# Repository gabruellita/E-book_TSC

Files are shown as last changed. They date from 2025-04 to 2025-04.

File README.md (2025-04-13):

# OpenBook E-Book Reader

Bine ați venit la proiectul OpenBook, un cititor de e-bookuri open-source, accesibil, conceput pentru a face lectura disponibilă tuturor. Acest repository conține fișierele de design hardware, fișierele de fabricație, modelele mecanice și documentația pentru dispozitivul OpenBook.

## Cuprins

- [Prezentare Proiect](#prezentare-proiect)
- [Diagramă Bloc](#diagrama-bloc)
- [Lista de Materiale (BOM)](#lista-de-materiale-bom)
- [Funcționalitate Hardware](#functionalitate-hardware)
- [Alocarea Pinilor ESP32-C6](#alocarea-pinilor-esp32-c6)
- [Note de Design](#note-de-design)
- [Licență](#licenta)

## Prezentare Proiect

OpenBook este un cititor de e-bookuri open-source bazat pe microcontrolerul ESP32-C6. Dispozitivul include un display e-paper, stocare pe card SD pentru e-bookuri, o interfață USB-C pentru alimentare și date, și un design compact care se potrivește într-o carcasă personalizată. Scopul este crearea unui e-reader ieftin, modificabil, care poate fi produs în masă, respectând principiile open-source.

Acest repository conține:

- **Hardware**: Fișiere pentru schemă electrică și PCB.
- **Manufacturing**: Fișiere Gerber, Lista de Materiale (BOM) și fișiere Pick and Place.
- **Mechanical**: Modele 3D ale dispozitivului complet (PCB, baterie, display și carcasă).
- **Images**: Randări ale PCB-ului și dispozitivului.

## Diagramă Bloc

Mai jos este o diagramă bloc care ilustrează componentele principale și conexiunile lor:

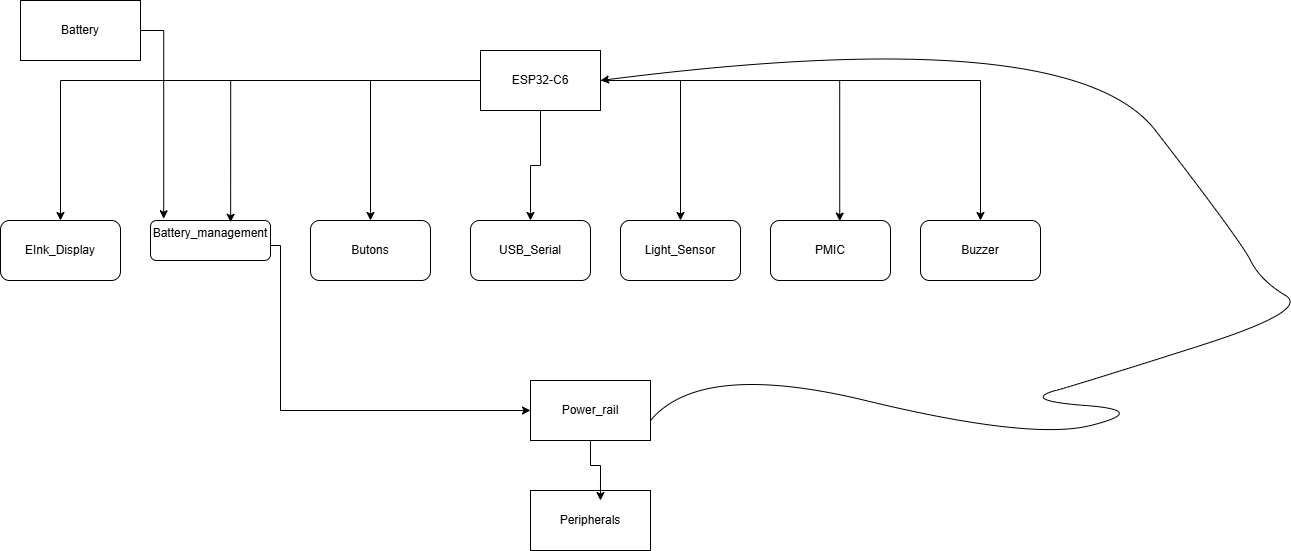
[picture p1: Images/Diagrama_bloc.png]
Diagramă Bloc


*(Notă: Creează o diagramă folosind Draw.io sau Lucidchart, export-o ca PNG și încarc-o în folderul `Images`. Actualizează link-ul de mai sus dacă numele fișierului este diferit.)*

## Lista de Materiale (BOM)

Tabelul următor listează componentele folosite în designul OpenBook, cu link-uri către furnizori și datasheet-uri.

| Componentă | Număr Piesă | Cantitate | Link Furnizor | Link Datasheet | Note |
|---|---|---|---|---|---|
| Senzor mediu | BME680 | 1 | [SnapEDA](https://www.snapeda.com/parts/BME680/Bosch/view-part/?welcome=home) | [Bosch](https://www.bosch-sensortec.com/media/boschsensortec/downloads/datasheets/bst-bme680-ds001.pdf) | Senzor temperatură, umiditate |
| Buton tactil | EVQPUJ02K | 3 | [Panasonic](https://industry.panasonic.com/global/en/products/control/switch/light-touch/number/evqpuj02k) | [LCSC](https://www.lcsc.com/datasheet/lcsc_datasheet_2201121800_PANASONIC-EVQPUJ02K_C2936858.pdf) | Butoane navigare și pornire |
| Condensator | R0402 100K | [TBD] | [ComponentSearch](https://componentsearchengine.com/part-view/R0402%201%25%20100%20K%20(RC0402FR-07100KL)/YAGEO) | [Resistor](https://www.resistor.com/assets/pdf/0402tstd.pdf) | Condensator decuplare, SMD 0402 |
| Rezistor | R0402 100K | [TBD] | [ComponentSearch](https://componentsearchengine.com/part-view/R0402%201%25%20100%20K%20(RC0402FR-07100KL)/YAGEO) | [Resistor](https://www.resistor.com/assets/pdf/0402tstd.pdf) | Rezistor, SMD 0402 |
| Baterie | CPH3225A | 1 | [SnapEDA](https://www.snapeda.com/parts/CPH3225A/Seiko+Instruments/view-part/?ref=eda) | [Octopart](https://octopart.com/datasheet/cph3225a-seiko-25340571) | Baterie Li-Po, ~500mAh |
| LED | KP-1608SURCK | 1 | [SnapEDA](https://www.snapeda.com/parts/KP-1608SURCK/Kingbright/view-part/?ref=search&t=LED%200603) | [ELV](https://media.elv.com/file/107153_led_surck1608_data.pdf) | LED 0603, indicator |
| Protecție ESD | USBLC6-2SC6Y | 1 | [SnapEDA](https://www.snapeda.com/parts/USBLC6-2SC6Y/STMicroelectronics/view-part/?ref=eda) | [DigiKey](https://www.digikey.com/en/htmldatasheets/production/1375342/0/0/1/usblc6-2sc6y) | Protecție USB |
| Diodă Schottky | SD0805S020S1R0 | 1 | [Mouser](https://ro.mouser.com/ProductDetail/KYOCERA-AVX/SD0805S020S1R0?qs=jCA%252BPfw4LHbpkAoSnwrdjw%3D%3D) | [AllDataSheet](https://www.alldatasheet.com/view.jsp?Searchword=SD0805S&sField=2) | Diodă pentru alimentare |
| Supresor ESD | PGB1010603MR | 1 | [SnapEDA](https://www.snapeda.com/parts/PGB1010603MR/Littelfuse/view-part/?ref=eda) | [AllDataSheet](https://www.alldatasheet.com/view.jsp?Searchword=Pgb1010603mr) | Protecție ESD |
| Detector tensiune | BD5229G-TR | 1 | [ComponentSearch](https://componentsearchengine.com/part-view/BD5229G-TR/ROHM%20Semiconductor) | [LCSC](https://www.lcsc.com/datasheet/lcsc_datasheet_2201131330_ROHM-Semicon-BD5229G-TR_C962636.pdf) | Monitorizare tensiune |
| Regulator tensiune | XC6220A331MR-G | 1 | [ComponentSearch](https://componentsearchengine.com/part-view/XC6220A331MR-G/Torex) | [AllDataSheet](https://www.alldatasheet.com/view.jsp?Searchword=Xc6220) | Regulator 3.3V |
| Conector USB-C | USB4110-GF-A | 1 | [ComponentSearch](https://componentsearchengine.com/part-view/USB4110-GF-A/GCT%20(GLOBAL%20CONNECTOR%20TECHNOLOGY)) | [GCT](https://gct.co/files/drawings/usb4110.pdf) | Interfață USB-C |
| LED | LEDCHIP-LED0603 | 1 | [Mouser](https://eu.mouser.com/ProductDetail/Adafruit/4208?qs=PzGy0jfpSMtbScLbr0L5dw%3D%3D) | [Arrow](https://www.arrow.com/en/manufacturers/adafruit-industries/datasheets) | LED 0603, Adafruit |
| Bobină | [TBD] | 1 | [Comet](https://store.comet.srl.ro/Catalogue/Product/43497/) | [Scribd](https://www.scribd.com/document/814581278/Datasheet-Bobina) | Inductor pentru alimentare |
| Siguranță resetabilă | PFMF | 1 | [Mouser](https://www.mouser.co.uk/ProductDetail/EPCOS-TDK/B72520T0350K062?qs=dEfas%2FXlABIszF52uu7vrg%3D%3D) | [Mouser](https://ro.mouser.com/c/ds/circuit-protection/thermistors/resettable-fuses-pptc/?m=Schurter&series=PFMF) | Protecție circuit |
| MOSFET | DMG2305UX-7 | 1 | [ComponentSearch](https://componentsearchengine.com/part-view/DMG2305UX-7/Diodes%20Incorporated) | [Mouser](https://www.mouser.com/datasheet/2/115/DMG2305UX-266242.pdf) | Comutare putere |
| MOSFET | Si1308EDL-T1-GE3 | 1 | [ComponentSearch](https://componentsearchengine.com/part-view/SI1308EDL-T1-GE3/Vishay) | [AllDataSheet](https://www.alldatasheet.com/view.jsp?Searchword=Si1308edl) | Comutare putere |
| IC management baterie | MCP73831T-5ACI/OT | 1 | [Mouser](https://www.mouser.co.uk/ProductDetail/Microchip-Technology/MCP73831T-5ACI-OT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) | [Microchip](https://ww1.microchip.com/downloads/en/DeviceDoc/MCP73831-Family-Data-Sheet-DS20001984H.pdf) | Încărcare baterie |
| Lipire SMD | SMD Solder | [TBD] | [GrabCAD](https://grabcad.com/library/solder-jumpers-1) | - | Pentru asamblare SMD |
| Memorie flash | W25Q512JVEIQ | 1 | [SnapEDA](https://www.snapeda.com/parts/W25Q512JVEIQ/Winbond+Electronics/view-part/) | [Mouser](https://www.mouser.com/datasheet/2/949/W25Q512JV_SPI_RevB_06252019_KMS-2487502.pdf) | Memorie SPI |
| Modul microcontroler | ESP32-C6-WROOM-1-N8 | 1 | [SnapEDA](https://www.snapeda.com/parts/ESP32-C6-WROOM-1-N8/Espressif+Systems/view-part/?ref=eda) | [Mouser](https://www.mouser.com/catalog/specsheets/Espressif_ESP32_C6_WROOM_1%20_Datasheet_V0.1_PRELIMINARY_en.pdf) | Modul Wi-Fi/Bluetooth |
| Ceas timp real | DS3231SN# | 1 | [SnapEDA](https://www.snapeda.com/parts/DS3231SN%23/Analog+Devices/view-part/?ref=eda) | [AllDataSheet](https://www.alldatasheet.com/view.jsp?Searchword=Ds3231sn%20datasheet) | RTC pentru timp |
| Monitor baterie | MAX17048G+T10 | 1 | [SnapEDA](https://www.snapeda.com/parts/MAX17048G+T10/Analog+Devices/view-part/?ref=eda) | [AllDataSheet](https://www.alldatasheet.com/view.jsp?Searchword=Max17048) | Monitorizare nivel baterie |

## Funcționalitate Hardware

Hardware-ul OpenBook este proiectat pentru a echilibra costul, eficiența energetică și funcționalitatea. Caracteristicile principale includ:

- **Microcontroler ESP32-C6**:
  - **Nucleu**: Procesor RISC-V single-core.
  - **Conectivitate**: Wi-Fi 6 și Bluetooth 5 pentru actualizări de firmware sau integrare cloud.
  - **Interfețe**: SPI pentru display și card SD, GPIO pentru butoane, USB pentru alimentare și depanare.
  - **Consum de energie**: Optimizat pentru funcționare cu consum redus, cu moduri de sleep pentru a prelungi durata bateriei.

- **Display E-Paper**:
  - Display e-paper de 2.13" (rezoluție [TBD, ex. 250x122 pixeli]).
  - Conectat prin SPI pentru actualizare rapidă și consum redus.
  - Ideal pentru citit în diverse condiții de iluminare, cu consum minim.

- **Modul Card SD**:
  - Stochează e-bookuri și alte fișiere media.
  - Conectat prin SPI pentru transfer de date fiabil.
  - Suportă carduri microSD standard.

- **Interfață USB-C**:
  - Furnizează alimentare (intrare 5V) și încarcă bateria prin IC-ul de management al puterii.
  - Suportă transfer de date pentru depanare sau actualizări de firmware.

- **Baterie și Management Putere**:
  - Baterie Li-Po de 3.7V (~500mAh, capacitate exactă [TBD]).
  - IC de management al puterii (ex. TP4056) gestionează încărcarea și reglarea tensiunii (3.3V pentru ESP32 și alte componente).
  - Durata estimată a bateriei: [TBD, ex. 20 ore de citire activă], bazată pe calcule pentru actualizarea display-ului, modurile sleep ale ESP32 și accesul la cardul SD.

- **Butoane**:
  - Trei butoane tactile pentru navigare (următoarea/pagina anterioară) și pornire/meniu.
  - Conectate la pinii GPIO ai ESP32 cu rezistoare pull-up.

- **Calcule Consum Energie**:
  - ESP32-C6 (activ): ~100mA la 3.3V.
  - Display E-Paper (actualizare): ~10mA pentru 1s per pagină.
  - Card SD (citire): ~50mA în timpul accesului.
  - Consum total activ: [TBD, ex. ~150mA mediu].
  - Mod sleep: [TBD, ex. <1mA].

*(Notă: Actualizează consumul de energie și alte specificații pe baza alegerilor tale de design și a datasheet-urilor.)*

## Alocarea Pinilor ESP32-C6

Pinii ESP32-C6 sunt alocați astfel:

| Pin | Funcție | Componentă/Modul | Note |
|---|---|---|---|
| GPIO0 | SPI MOSI | Display E-Paper, Card SD| Bus SPI comun |
| GPIO1 | SPI MISO | Display E-Paper, Card SD| Bus SPI comun |
| GPIO2 | SPI SCK | Display E-Paper, Card SD| Bus SPI comun |
| GPIO3 | SPI CS (Display) | Display E-Paper | Selectare cip pentru display |
| GPIO4 | SPI CS (Card SD) | Modul Card SD | Selectare cip pentru card SD |
| GPIO5 | Buton 1 (Pagina Urm.) | Buton Tactil | Pull-up, activ low |
| GPIO6 | Buton 2 (Pagina Ant.) | Buton Tactil | Pull-up, activ low |
| GPIO7 | Buton 3 (Pornire/Meniu) | Buton Tactil | Pull-up, activ low |
| GPIO8 | Reset Display | Display E-Paper | Activ low |
| GPIO9 | Busy Display | Display E-Paper | Intrare de la display |
| VBUS | Alimentare USB | Conector USB-C | Intrare 5V |
| 3V3 | Linie Alimentare | Toate componentele | Reglat din baterie/USB |

*(Notă: Verifică alocarea pinilor față de schemă. Actualizează tabelul cu numerele exacte ale pinilor și funcțiile pe baza designului tău.)*

### De ce acești pini?

- **Pini SPI (GPIO0-4)**: Aleși pentru suportul hardware dedicat SPI, asigurând comunicație rapidă și fiabilă cu display-ul și cardul SD. Un bus SPI comun minimizează utilizarea pinilor.
- **Pini Butoane (GPIO5-7)**: Selectați pentru capabilitățile de intrare generală și suport pentru întreruperi, permițând interacțiune rapidă cu utilizatorul.
- **Pini Control Display (GPIO8-9)**: Folosiți pentru semnalele de reset și busy, conform cerințelor datasheet-ului display-ului e-paper.
- **Pini Alimentare (VBUS, 3V3)**: Standard pentru livrarea și reglarea energiei.

## Note de Design

- **Schemă și Design PCB**:
  - Schema (`Hardware/openbook.sch`) respectă referința furnizată.
  - Layout-ul PCB (`Hardware/openbook.brd`) respectă constrângerile mecanice, cu toate componentele pe stratul TOP și rutarea pe ambele straturi TOP și BOTTOM.
  - Traseele de alimentare folosesc lățimea de 0.3mm, iar traseele de semnal au lățimea minimă de 0.15mm, conform ghidului.
  - Antena ESP32-C6 este poziționată la marginea PCB-ului, cu o decupare dedesubt pentru a minimiza interferențele.

- **Design Mecanic**:
  - Modelul 3D (`Mechanical/openbook.step`) include PCB-ul, bateria, display-ul e-paper și carcasa modificată.
  - Bateria se conectează direct la pad-uri de test (fără conector JST) pentru a economisi spațiu.
  - Carcasa a fost modificată pentru a alinia portul USB-C și slotul pentru card SD (detalii în folderul `Mechanical`).

- **Provocări și Decizii**:
  - **erori DRC**: Ignorate erorile „Only INPUT pins on NET ID” și erorile de dimensiune pentru butoane/USB, conform ghidului, deoarece nu afectează funcționalitatea.
  - **Amplasare componente**: Componentele au fost grupate în jurul ESP32 și al driverului display-ului pentru a minimiza lungimea traseelor și a îmbunătăți integritatea semnalului.
  - **Via Stitching**: Aplicat între planurile de masă TOP și BOTTOM lângă ESP32 pentru a îmbunătăți performanța EMI.
  - **Silkscreen**: Include doar numele componentelor (nu și valorile) pentru claritate, respectând bunele practici.

## Licență

Acest proiect este licențiat sub [GNU General Public License v3.0](LICENSE). Puteți utiliza, modifica și distribui designul, cu condiția respectării termenilor licenței.

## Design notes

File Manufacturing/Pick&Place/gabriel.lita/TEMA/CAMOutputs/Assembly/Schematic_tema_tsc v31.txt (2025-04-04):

Partlist exported from Fusion Hub: gabriel.lita   Project: TEMA  Board: Schematic_tema_tsc v31 at 4/4/2025 6:59 PM

Qty Value                                                                          Device                                                                         Package                                                Parts                                                                                                   Description                                                                                                                                                                                                                                                                                                                                                                                                                                                                                          ARROW_PART_NUMBER ARROW_PRICE-STOCK AVAILABILITY CENTROID_NOT_SPECIFIED CHECK_PRICES                                                                           COPYRIGHT                                                DATASHEET                              DESCRIPTION                                                                                        DIGIKEY_DESCRIPTION                                                                                                                                                                                                      DIGIKEY_PART_NUMBER                           HEIGHT                                                                                LEAD_FREE                                                          MANUFACTURER_NAME                 MANUFACTURER_PART_NUMBER MF                  MFR_NAME          MOUSER_PART_NUMBER    MOUSER_PRICE-STOCK                                                                                        MOUSER_TESTING_PART_NUMBER MOUSER_TESTING_PRICE-STOCK MP                                                                                                                  MPN                                                                                                  PACKAGE                     POPULARITY          PREFIX PRICE                        PROD_ID    PURCHASE-URL                                                                                                                                ROHS SNAPEDA_LINK                                                                       SPICEMODEL                                                                                                                                      SPICEPREFIX TEMPERATURE_RANGE_HIGH                                                                  TEMPERATURE_RANGE_LOW TP_SIGNAL_NAME VALUE             
1                                                                                  ADAFRUIT_LEDCHIP-LED0603                                                       ADAFRUIT_CHIP-LED0603                                  CHG_LED                                                                                                 LED                                                                                                                                                                                                                                                                                                                                                                                                                                                                                                                                                                                                                                                                                                                                                                                                                                                                                                                                                                                                                                                                                                                                                                                                                                                                                                                                                                                                                                                                                                                                                                                                                                                                                                                                                                                                                                                                                                                                                                                                                                                                                                                                                                                                                                                                                                                                                                                                                                                                  
1                                                                                  SJ                                                                             SJ                                                     SJ1                                                                                                     SMD solder JUMPER                                                                                                                                                                                                                                                                                                                                                                                                                                                                                                                                                                                                                                                                                                                                                                                                                                                                                                                                                                                                                                                                                                                                                                                                                                                                                                                                                                                                                                                                                                                                                                                                                                                                                                                                                                                                                                  3                                                                                                                                                                                                                                                                                                                                                                                                                                                                                                                                                                                                                 
1   0.1uF                                                                          EAGLE-LTSPICE_CC0402                                                           EAGLE-LTSPICE_C0402                                    EPD_C5                                                                                                  CAPACITOR, European symbol                                                                                                                                                                                                                                                                                                                                                                                                                                                                                                                                                                                                                                                                                                                                                                                                                                                                                                                                                                                                                                                                                                                                                                                                                                                                                                                                                                                                                                                                                                                                                                                                                                                                                                                                                                                                                                                                                                                                                                                                                                                                                                                                NONE                                                                                                                                            C                                                                                                                                                          
1   0.47                                                                           ESP32_WROVER_EAGLE-LTSPICE_RR0402                                              ESP32_WROVER_EAGLE-LTSPICE_R0402                       R3                                                                                                      RESISTOR, European symbol                                                                                                                                                                                                                                                                                                                                                                                                                                                                                                                                                                                                                                                                                                                                                                                                                                                                                                                                                                                                                                                                                                                                                                                                                                                                                                                                                                                                                                                                                                                                                                                                                                                                                                                                                                                                                                                                                                                                                                                                                                                                                                                                 NONE                                                                                                                                            R                                                                                                                                                          
1   100K                                                                           ESP32_WROVER_EAGLE-LTSPICE_RR0402                                              ESP32_WROVER_EAGLE-LTSPICE_R0402                       R1_PWRUSB                                                                                               RESISTOR, European symbol                                                                                                                                                                                                                                                                                                                                                                                                                                                                                                                                                                                                                                                                                                                                                                                                                                                                                                                                                                                                                                                                                                                                                                                                                                                                                                                                                                                                                                                                                                                                                                                                                                                                                                                                                                                                                                                                                                                                                                                                                                                                                                                                 NONE                                                                                                                                            R                                                                                                                                                          
8   100nF                                                                          EAGLE-LTSPICE_CC0402                                                           EAGLE-LTSPICE_C0402                                    C1, C2, C4_USB, C6, C8, C9, C10, C_DELAY                                                                CAPACITOR, European symbol                                                                                                                                                                                                                                                                                                                                                                                                                                                                                                                                                                                                                                                                                                                                                                                                                                                                                                                                                                                                                                                                                                                                                                                                                                                                                                                                                                                                                                                                                                                                                                                                                                                                                                                                                                                                                                                                                                                                                                                                                                                                                                                                NONE                                                                                                                                            C                                                                                                                                                          
1   100uF                                                                          RCL_CPOL-EUCT3528                                                              RCL_CT3528                                             C3                                                                                                      POLARIZED CAPACITOR, European symbol                                                                                                                                                                                                                                                                                                                                                                                                                                                                                                                                                                                                                                                                                                                                                                                                                                                                                                                                                                                                                                                                                                                                                                                                                                                                                                                                                                                                                                                                                                                                                                                                                                                                                                                                                                                                               0                                                                                                                                                                                                                                                                                                                                                                                                                                                      C                                                                                                                                                          
16  10K                                                                            ESP32_WROVER_EAGLE-LTSPICE_RR0402                                              ESP32_WROVER_EAGLE-LTSPICE_R0402                       R1, R1_PINH, R1_PINH1, R2_PINH, R2_PINH1, R4, R5, R6, R7, R8, R9, R10, R_BOOT, R_CHANGE, R_CL1, R_RESET RESISTOR, European symbol                                                                                                                                                                                                                                                                                                                                                                                                                                                                                                                                                                                                                                                                                                                                                                                                                                                                                                                                                                                                                                                                                                                                                                                                                                                                                                                                                                                                                                                                                                                                                                                                                                                                                                                                                                                                                                                                                                                                                                                                                                                                                                                                 NONE                                                                                                                                            R                                                                                                                                                          
1   10uF                                                                           EAGLE-LTSPICE_CC0402                                                           EAGLE-LTSPICE_C0402                                    C7                                                                                                      CAPACITOR, European symbol                                                                                                                                                                                                                                                                                                                                                                                                                                                                                                                                                                                                                                                                                                                                                                                                                                                                                                                                                                                                                                                                                                                                                                                                                                                                                                                                                                                                                                                                                                                                                                                                                                                                                                                                                                                                                                                                                                                                                                                                                                                                                                                                NONE                                                                                                                                            C                                                                                                                                                          
1   112A-TAAR-R03_ATTEND                                                           112A-TAAR-R03_ATTEND                                                           112ATAARR03ATTEND                                      J4                                                                                                      Micro SD Card Socket, Push-Push Type, Top Mount, SMT, H=1.83mm, 10u                                                                                                                                                                                                                                                                                                                                                                                                                                                                                                                                                                                                                                                                                                 Micro SD Card Socket                                                                                Push-Push Type                                                                                                                                                                                                           Top Mount                                     SMT                                                                                   H=1.83mm                                                           10u                                                                           1.9mm                                   ATTEND                                                                                                    112A-TAAR-R03 ATTEND                                                                                                                                                                                                                                                                                                                                                                                                                                                                                                                                                                                                                                                                                                                                                                                                                                                                                                         
1   15                                                                             ESP32_WROVER_EAGLE-LTSPICE_RR0402                                              ESP32_WROVER_EAGLE-LTSPICE_R0402                       R_CAPACITOR                                                                                             RESISTOR, European symbol                                                                                                                                                                                                                                                                                                                                                                                                                                                                                                                                                                                                                                                                                                                                                                                                                                                                                                                                                                                                                                                                                                                                                                                                                                                                                                                                                                                                                                                                                                                                                                                                                                                                                                                                                                                                                                                                                                                                                                                                                                                                                                                                 NONE                                                                                                                                            R                                                                                                                                                          
1   1uF                                                                            EAGLE-LTSPICE_CC0402                                                           EAGLE-LTSPICE_C0402                                    C5                                                                                                      CAPACITOR, European symbol                                                                                                                                                                                                                                                                                                                                                                                                                                                                                                                                                                                                                                                                                                                                                                                                                                                                                                                                                                                                                                                                                                                                                                                                                                                                                                                                                                                                                                                                                                                                                                                                                                                                                                                                                                                                                                                                                                                                                                                                                                                                                                                                NONE                                                                                                                                            C                                                                                                                                                          
9   1uF/50V                                                                        EAGLE-LTSPICE_CC0402                                                           EAGLE-LTSPICE_C0402                                    EPD_C1, EPD_C2, EPD_C6, EPD_C7, EPD_C8, EPD_C9, EPD_C10, EPD_C11, EPD_C12                               CAPACITOR, European symbol                                                                                                                                                                                                                                                                                                                                                                                                                                                                                                                                                                                                                                                                                                                                                                                                                                                                                                                                                                                                                                                                                                                                                                                                                                                                                                                                                                                                                                                                                                                                                                                                                                                                                                                                                                                                                                                                                                                                                                                                                                                                                                                                NONE                                                                                                                                            C                                                                                                                                                          
1   2.2                                                                            ESP32_WROVER_EAGLE-LTSPICE_RR0402                                              ESP32_WROVER_EAGLE-LTSPICE_R0402                       R2                                                                                                      RESISTOR, European symbol                                                                                                                                                                                                                                                                                                                                                                                                                                                                                                                                                                                                                                                                                                                                                                                                                                                                                                                                                                                                                                                                                                                                                                                                                                                                                                                                                                                                                                                                                                                                                                                                                                                                                                                                                                                                                                                                                                                                                                                                                                                                                                                                 NONE                                                                                                                                            R                                                                                                                                                          
1   200                                                                            ESP32_WROVER_EAGLE-LTSPICE_RR0402                                              ESP32_WROVER_EAGLE-LTSPICE_R0402                       R1_BAT                                                                                                  RESISTOR, European symbol                                                                                                                                                                                                                                                                                                                                                                                                                                                                                                                                                                                                                                                                                                                                                                                                                                                                                                                                                                                                                                                                                                                                                                                                                                                                                                                                                                                                                                                                                                                                                                                                                                                                                                                                                                                                                                                                                                                                                                                                                                                                                                                                 NONE                                                                                                                                            R                                                                                                                                                          
2   20V/4.2A/52mO/1.4W                                                             ESP32_WROVER_SPARKFUN-DISCRETESEMI_MOSFET_PCH-DMG2305UX-7                      ESP32_WROVER_SPARKFUN-DISCRETESEMI_SOT23-3             Q1, Q2                                                                                                  P-channel MOSFETs                                                                                                                                                                                                                                                                                                                                                                                                                                                                                                                                                                                                                                                                                                                                                                                                                                                                                                                                                                                                                                                                                                                                                                                                                                                                                                                                                                                                                                                                                                                                                                                                                                                                                                                                                                                                                                                                                          TRAN-14388                                                                                                                                                                                                                                                                                                                                                                                                                                                                                                                              20V/4.2A/52mO/1.4W
1   2K                                                                             ESP32_WROVER_EAGLE-LTSPICE_RR0402                                              ESP32_WROVER_EAGLE-LTSPICE_R0402                       R2_BAT                                                                                                  RESISTOR, European symbol                                                                                                                                                                                                                                                                                                                                                                                                                                                                                                                                                                                                                                                                                                                                                                                                                                                                                                                                                                                                                                                                                                                                                                                                                                                                                                                                                                                                                                                                                                                                                                                                                                                                                                                                                                                                                                                                                                                                                                                                                                                                                                                                 NONE                                                                                                                                            R                                                                                                                                                          
5   4.7uF                                                                          EAGLE-LTSPICE_CC0402                                                           EAGLE-LTSPICE_C0402                                    C1_BAT, C1_BAT1, C2_BAT, C2_BAT2, C5_USB                                                                CAPACITOR, European symbol                                                                                                                                                                                                                                                                                                                                                                                                                                                                                                                                                                                                                                                                                                                                                                                                                                                                                                                                                                                                                                                                                                                                                                                                                                                                                                                                                                                                                                                                                                                                                                                                                                                                                                                                                                                                                                                                                                                                                                                                                                                                                                                                NONE                                                                                                                                            C                                                                                                                                                          
1   4.7uF/25V                                                                      EAGLE-LTSPICE_CC0402                                                           EAGLE-LTSPICE_C0402                                    C4                                                                                                      CAPACITOR, European symbol                                                                                                                                                                                                                                                                                                                                                                                                                                                                                                                                                                                                                                                                                                                                                                                                                                                                                                                                                                                                                                                                                                                                                                                                                                                                                                                                                                                                                                                                                                                                                                                                                                                                                                                                                                                                                                                                                                                                                                                                                                                                                                                                NONE                                                                                                                                            C                                                                                                                                                          
2   5k1                                                                            ESP32_WROVER_EAGLE-LTSPICE_RR0402                                              ESP32_WROVER_EAGLE-LTSPICE_R0402                       R2-USB, R2-USB1                                                                                         RESISTOR, European symbol                                                                                                                                                                                                                                                                                                                                                                                                                                                                                                                                                                                                                                                                                                                                                                                                                                                                                                                                                                                                                                                                                                                                                                                                                                                                                                                                                                                                                                                                                                                                                                                                                                                                                                                                                                                                                                                                                                                                                                                                                                                                                                                                 NONE                                                                                                                                            R                                                                                                                                                          
1   68uF                                                                           744043680IND_4828-WE-TPC_WRE                                                   IND_4828-WE-TPC_WRE                                    L1                                                                                                                                                                                                                                                                                                                                                                                                                                                                                                                                                                                                                                                                                                                                                                          Copyright (C) 2024 Ultra Librarian. All rights reserved.                                                                                                                                                                                                                                                                                                                                                                                                                                                                                                                                                                                                             744043680                                    Wurth Electronics                                                                                                                                                                                                                                                                                                                                                                                                                                                                                                                                                                                                                                                                                                                                                                                                                                                                                                                                                                                                                                                              
1   BD5229G-TR                                                                     BD5229G-TR                                                                     SOT95P280X125-5N                                       IC1                                                                                                     Voltage Detector with Adjustable Delay Time: CMOS processes are utilized to develop high precision, low current consumption CMOS reset ICs that allow arbitrary setting of the delay time. The extensive lineup includes both Nch Open Drain and CMOS output types in a wide range of detection voltages (from 2.3V to 6.0V, in 0.1V steps), enabling selection of the ideal solution based on customer requirements. In addition, the entire series is of course both lead-free and RoHS-compliant.                                                                                                                                                                                                                                                                Voltage Detector with Adjustable Delay Time: CMOS processes are utilized to develop high precision  low current consumption CMOS reset ICs that allow arbitrary setting of the delay time. The extensive lineup includes both Nch Open Drain and CMOS output types in a wide range of detection voltages (from 2.3V to 6.0V  in 0.1V steps)                                enabling selection of the ideal solution based on customer requirements. In addition  the entire series is of course both lead-free and RoHS-compliant.                                                            1.25mm                                ROHM Semiconductor    BD5229G-TR                                                                                                                                                      755-BD5229G-TR                                                                                                      https://www.mouser.co.uk/ProductDetail/ROHM-Semiconductor/BD5229G-TR?qs=4kLU8WoGk0vvnhrrYwdszw%3D%3D                                                                                                                                                                                                                                                                                                                                                                                                                                                                                                                                                                                                                                               
3   BUTTON_CUSYOMV1                                                                BUTTON_CUSYOMV1                                                                MYBUTTON                                               BOOT_BUTTON, CHANGE_BUTTON, RESET_BUTTON                                                                                                                                                                                                                                                                                                                                                                                                                                                                                                                                                                                                                                                                                                                                                                                                                                                                                                                                                                                                                                                                                                                                                                                                                                                                                                                                                                                                                                                                                                                                                                                                                                                                                                                                                                                                                                                                                                                                                                                                                                                                                                                                                                                                                                                                                                                                                                                                                                                                                                                                     
1   CPH3225A                                                                       CPH3225A                                                                       CAPCP3225X100N                                         C10_SUPERCAP                                                                                            Cap 0.011F 3.3V 1210 Flat Check availability                                                                                                                                                                                                                                                                                                                                                                                                                                                                                             Not in stock                        https://www.snapeda.com/parts/CPH3225A/Seiko+Instruments/view-part/?ref=eda                                                                                                             11 mF (EDLC) Supercapacitor 3.3 V 1210 (3225 Metric) - -                                                                                                                                                                                                                                                                                                                                                                                                                                                                                                                                     Seiko Instruments                                                                                                                                                                                                           CPH3225A                                                                                                                                                                                                                 1210 Seiko                                             None                                    https://www.snapeda.com/api/url_track_click_mouser/?unipart_id=562593&manufacturer=Seiko Instruments&part_name=CPH3225A&search_term=None         https://www.snapeda.com/parts/CPH3225A/Seiko+Instruments/view-part/?ref=snap                                                                                                                                                                                                                                                                                                                  
1   DS3231SN#                                                                      DS3231SN#                                                                      SOIC127P1032X265-16N                                   U3                                                                                                      Real Time Clock Serial 16-Pin SOIC W T/R     Check availability                                                                                                                                                                                                                                                                                                                                                                                                                                                                          In Stock                            https://www.snapeda.com/parts/DS3231SN%23/Analog+Devices/view-part/?ref=eda                                                                                                             Extremely Accurate I²C-Integrated RTC/TCXO/Crystal                                                                                                                                                                                                                                                                                                                                                                                                                                                                                                                                           Analog Devices                                                                                                                                                                                                              DS3231SN#                                                                                                                                                                                                                SOIC-16 Maxim                                          None                                    https://www.snapeda.com/api/url_track_click_mouser/?unipart_id=99048&manufacturer=Analog Devices&part_name=DS3231SN#&search_term=None            https://www.snapeda.com/parts/DS3231SN%23/Analog+Devices/view-part/?ref=snap                                                                                                                                                                                                                                                                                                                  
1   ESP32-C6-WROOM-1-N8                                                            ESP32-C6-WROOM-1-N8                                                            XCVR_ESP32-C6-WROOM-1-N8                               U2                                                                                                      Check availability                                                                                                                                                                                                                                                                                                                                                                                                                                                                                                                       In Stock                            https://www.snapeda.com/parts/ESP32-C6-WROOM-1-N8/Espressif+Systems/view-part/?ref=eda                                                                                                  Multiprotocol Modules ESP32-C6 module                                                              Wi-Fi 6 in 2.4 GHz band                                                                                                                                                                                                  Bluetooth 5                                   Zigbee 3.0 and Thread. ESP34-WROOM Compatible - ENGINEERING SAMPLE                                                                                                                                                                                                             Espressif Systems                                                                                                                                                                                                                                                                                                                                                                                                    ESP32-C6-WROOM-1-N8        None                                                                                                                                                                                None                                                                                                                                                                                                                                                https://www.snapeda.com/parts/ESP32-C6-WROOM-1-N8/Espressif+Systems/view-part/?ref=snap                                                        
1   ESP32C6_VARISTORCN1812                                                         ESP32C6_VARISTORCN1812                                                         ESP32C6_VARISTOR_CT/CN1812                             PFMF.050.1                                                                                              VARISTOR                                                                                                                                                                                                                                                                                                                                                                                                                                                                                                                                                                                                                                                                                                                                                                                                                                                                                                                                                                                                                                                                                                                                                                                                                                                                                                                                                                                                                                                                                                                                                                                                                                                                                                                                                                                                                                           0                                                                                                                                                                                                                                                                                                                                                                                                                                                                                                                                                                                                                 
2   ESP32_WROVER_AVX---SD0805S020S1R0_AVX_SD0805S020S1R0_0_0AVX_SD0805S020S1R0_0_0 ESP32_WROVER_AVX---SD0805S020S1R0_AVX_SD0805S020S1R0_0_0AVX_SD0805S020S1R0_0_0 ESP32_WROVER_AVX---SD0805S020S1R0_AVX_SD0805S020S1R0_0 D2, D7                                                                                                  Schottky Barrier Rectifier Diode                                                                                                                                                                                                                                                                                                                                                                                                                                                                                                                      No                                                                                                                                                                     http://datasheets.avx.com/schottky.pdf                                                                                                    DIODE SCHOTTKY 20V 1A 0805                                                                                                                                                                                               478-7800-1-ND                                                                                                                       yes                                                                                                                           AVX                                   581-SD0805S020S1R0                                                                                                                                                                                                                                                                                                                                                                                             0805 (2012 metric)                              D                                                                                                                                                                                          yes                                                                                                                                                                                                                                                 +125°C                                                                                  -55°C                                                  
1   ESP32_WROVER_BME680_BME680                                                     ESP32_WROVER_BME680_BME680                                                     ESP32_WROVER_BME680_PSON80P300X300X100-8N              SENSOR2                                                                                                 Integrated Environmental Unit                                                                                                                                                                                                                                                                                                                                                                                                                                                                                                            Unavailable                                                                                                                                                                                                                 Integrated Environmental Unit                                                                                                                                                                                                                                                                                                                                                                                                                                                                                                                                                                Bosch Sensortec                                                                                                                                                                                                             BME680                                                                                                                                                                                                                   LGA-8 Bosch Tools                                      None                                                                                                                                                                                                                                                                                                                                                                                                                                                                                                                                                                                   
1   ESP32_WROVER_SPARKFUN-IC-POWER_MCP73831                                        ESP32_WROVER_SPARKFUN-IC-POWER_MCP73831                                        ESP32_WROVER_SPARKFUN-IC-POWER_SOT23-5                 MCP73831                                                                                                MCP73831T Li-Ion, Li-Pol Controller                                                                                                                                                                                                                                                                                                                                                                                                                                                                                                                                                                                                                                                                                                                                                                                                                                                                                                                                                                                                                                                                                                                                                                                                                                                                                                                                                                                                                                                                                                                                                                                                                                                                                                                                                                                                                                                                        IC-09995                                                                                                                                                                                                                                                                                                                                                                                                                                                                                                                                                  
1   FH34SRJ-24S-0.5SH_99_                                                          FH34SRJ-24S-0.5SH_99_                                                          FH34SRJ24S05SH99                                       J1                                                                                                      24 Position FFC, FPC Connector Contacts, Top and Bottom 0.020" (0.50mm) Surface Mount, Right Angle                                                                                                                                                                                                                                                                                                                                                                                                                                                                                                                                                                                                                                                                  24 Position FFC                                                                                     FPC Connector Contacts                                                                                                                                                                                                   Top and Bottom 0.020" (0.50mm) Surface Mount  Right Angle                                                                                                                                                                               1.1mm                                        Hirose            FH34SRJ-24S-0.5SH(99)                                                                                                                                      798-FH34SRJ24S05SH99       https://www.mouser.co.uk/ProductDetail/Hirose-Connector/FH34SRJ-24S-0.5SH99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                                                                                                                                                                                                                                                                                                                                                                                                                                                                                                                                                                                                                                                                                                                                                    
1   MAX17048G+T10                                                                  MAX17048G+T10                                                                  SON50P200X200X80-9N                                    U4                                                                                                      Check availability                                                                                                                                                                                                                                                                                                                                                                                                                                                                                                                       In Stock                            https://www.snapeda.com/parts/MAX17048G+T10/Analog+Devices/view-part/?ref=eda                                                                                                           3µA 1-Cell/2-Cell Fuel Gauge with ModelGauge                                                                                                                                                                                                                                                                                                                                                                                                                                                                                                                                                 Analog Devices                                                                                                                                                                                                              MAX17048G+T10                                                                                                                                                                                                            TDFN-8 Maxim                                           None                                    https://www.snapeda.com/api/url_track_click_mouser/?unipart_id=329239&manufacturer=Analog Devices&part_name=MAX17048G+T10&search_term=None       https://www.snapeda.com/parts/MAX17048G+T10/Analog+Devices/view-part/?ref=snap                                                                                                                                                                                                                                                                                                                
3   MBR0530                                                                        MBR0530                                                                        SOD3716X135N                                           D3, D4, D5                                                                                              ON SEMICONDUCTOR - MBR0530 - DIODE, SCHOTTKY, 0.5A, 30V, SOD-123                                                                                                                                                                                                                                                                                                                                                                                                                                                                         In Stock                            https://www.snapeda.com/parts/MBR0530/Onsemi/view-part/?ref=eda                                                                                                                         Diode Schottky 30 V 500mA Surface Mount SOD-123                                                                                                                                                                                                                                                                                                                                                                                                                                                                                                                                              ON Semiconductor                                                                                                                                                                                                            MBR0530                                                                                                                                                                                                                  SOD-123-2 ON Semiconductor                             None                                    https://www.snapeda.com/api/url_track_click_mouser/?unipart_id=179458&manufacturer=ON Semiconductor&part_name=MBR0530&search_term=None           https://www.snapeda.com/parts/MBR0530/Onsemi/view-part/?ref=snap                                                                                                                                                                                                                                                                                                                              
6   PGB1010603MR                                                                   PGB1010603MR                                                                   DIOC1608X36N                                           D6, D8, D9, D10, D11, D12                                                                               Check availability                                                                                                                                                                                                                                                                                                                                                                                                                                                                                                                       In Stock                            https://www.snapeda.com/parts/PGB1010603MR/Littelfuse/view-part/?ref=eda                                                                                                                150V (Typ) Clamp - Ipp Tvs Diode Surface Mount 0603 (1608 Metric)                                                                                                                                                                                                                                                                                                                                                                                                                                                                                                                            Littelfuse Inc.                                                                                                                                                                                                             PGB1010603MR                                                                                                                                                                                                             0603 Littelfuse Inc.                                   None                                    https://www.snapeda.com/api/url_track_click_mouser/?unipart_id=5659453&manufacturer=Littelfuse Inc.&part_name=PGB1010603MR&search_term=None      https://www.snapeda.com/parts/PGB1010603MR/Littelfuse/view-part/?ref=snap                                                                                                                                                                                                                                                                                                                     
1   QWIIC_RIGHT_ANGLE                                                              QWIIC_CONNECTORJS-1MM                                                          JST04_1MM_RA                                           J3                                                                                                      SparkFun I2C Standard Qwiic Connector                                                                                                                                                                                                                                                                                                                                                                                                                                                                                                                                                                                                                                                                                                                                                                                                                                                                                                                                                                                                                                                                                                                                                                                                                                                                                                                                                                                                                                                                                                                                                                                                                                                                                                                                                                                                                                                                      CONN-13694                                                                                                                                                                                                                                                                                                                                                                                                                                                                                                                              QWIIC_RIGHT_ANGLE 
1   SAMACSYS_PARTS_USB4110-GF-A                                                    SAMACSYS_PARTS_USB4110-GF-A                                                    SAMACSYS_PARTS_USB4110GFA                              J2                                                                                                      CONN USB 2.0 TYPE-C R/A SMT                                                                                                                                                                                                                                                                                                                                                                                                                                                                                                                                                                                                                                                                                                                                         CONN USB 2.0 TYPE-C R/A SMT                                                                                                                                                                                                                                                                                                                                               3.26mm                                                                                                                                                   GCT (GLOBAL CONNECTOR TECHNOLOGY) USB4110-GF-A                                                   640-USB4110-GF-A      https://www.mouser.co.uk/ProductDetail/GCT/USB4110-GF-A?qs=KUoIvG%2F9IlYiZvIXQjyJeA%3D%3D
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

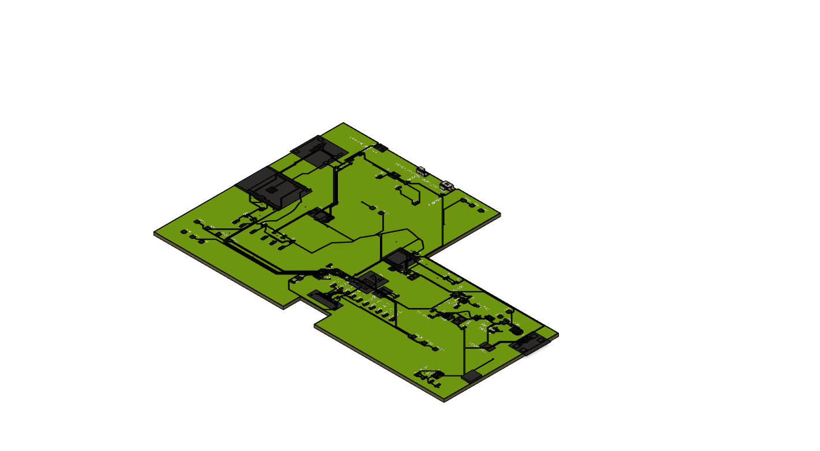
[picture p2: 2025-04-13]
Images/Schematic_tema_tsc_finalll v1.png

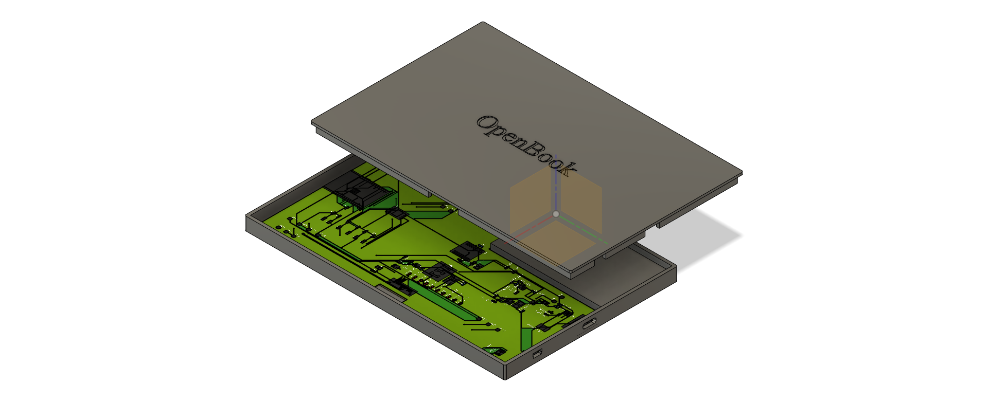
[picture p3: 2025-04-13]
Images/OpenBook Enclosure v2.png

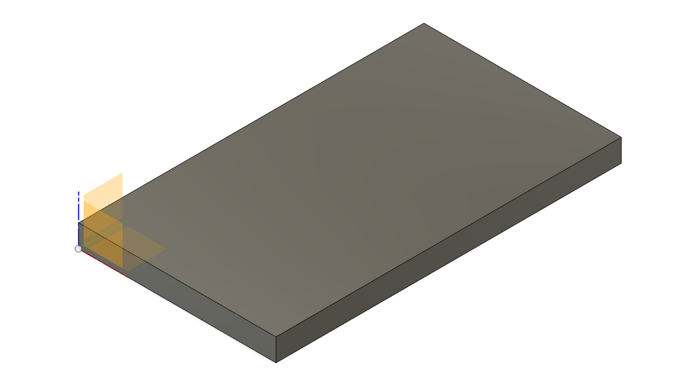
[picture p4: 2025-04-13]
Images/Battery v2.png

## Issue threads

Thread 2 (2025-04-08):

3d PCB

stefy-d, 2025-04-08:
- Trebuie să adăugați modelul 3D al PCB, cu toate componentele de pe el.
- O resursă foarte utilă pentru componente și modelele 3D ale lor este [Component Search Engine](https://componentsearchengine.com/)

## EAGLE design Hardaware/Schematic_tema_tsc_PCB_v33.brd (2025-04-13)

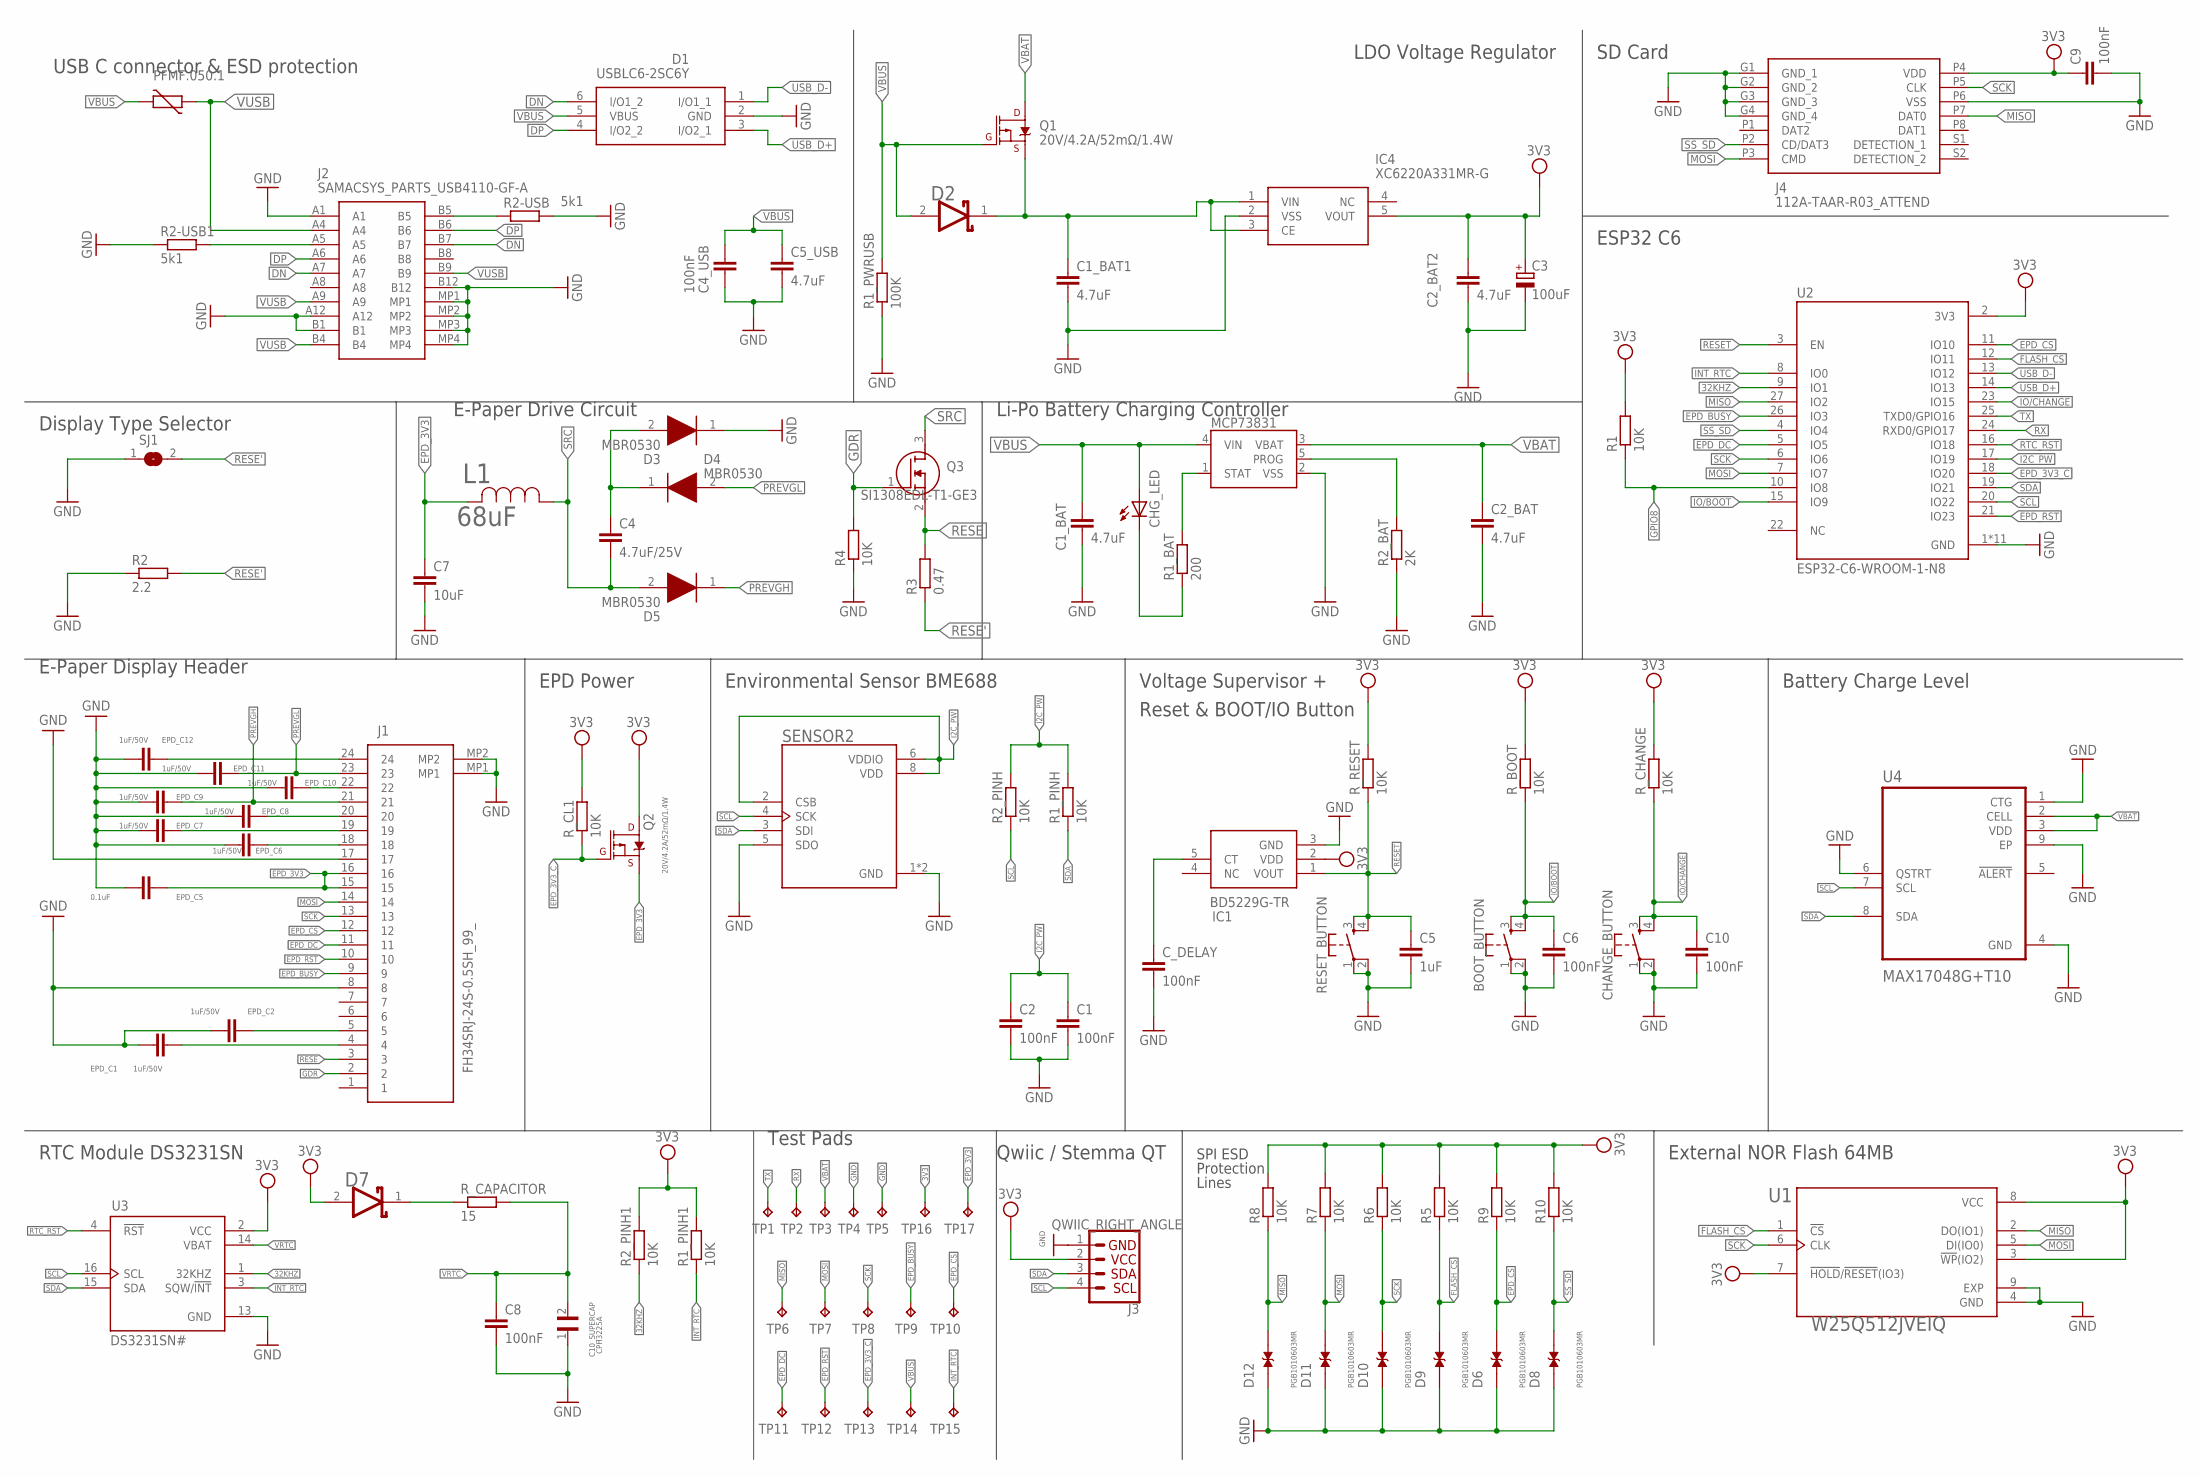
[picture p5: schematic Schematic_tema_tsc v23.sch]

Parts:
BOOT_BUTTON: BUTTON_CUSYOMV1; MYBUTTON
C1, C2, C4_USB, C6, C8, C9, C10: 100nF; EAGLE-LTSPICE_C0402
C1_BAT, C1_BAT1, C2_BAT, C2_BAT2, C5_USB: 4.7uF; EAGLE-LTSPICE_C0402
C3: 100uF; RCL_CT3528
C4: 4.7uF/25V; EAGLE-LTSPICE_C0402
C5: 1uF; EAGLE-LTSPICE_C0402
C7: 10uF; EAGLE-LTSPICE_C0402
C10_SUPERCAP: CPH3225A; CAPCP3225X100N
CHANGE_BUTTON: BUTTON_CUSYOMV1; MYBUTTON
CHG_LED: ADAFRUIT_LEDCHIP-LED0603; ADAFRUIT_CHIP-LED0603
C_DELAY: 100nF; EAGLE-LTSPICE_C0402
D1: USBLC6-2SC6Y; SOT95P280X145-6N
D2, D7: ESP32_WROVER_AVX---SD0805S020S1R0_AVX_SD0805S020S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; ESP32_WROVER_AVX---SD0805S020S1R0_AVX_SD0805S020S1R0_0
D3, D4, D5: MBR0530; SOD3716X135N
D6, D8, D9, D10, D11, D12: PGB1010603MR; DIOC1608X36N
EPD_C1, EPD_C2, EPD_C6, EPD_C7, EPD_C8, EPD_C9, EPD_C10, EPD_C11, EPD_C12: 1uF/50V; EAGLE-LTSPICE_C0402
EPD_C5: 0.1uF; EAGLE-LTSPICE_C0402
IC1: BD5229G-TR; SOT95P280X125-5N
IC4: XC6220A331MR-G; SOT95P280X120-5N
J1: FH34SRJ-24S-0.5SH_99_; FH34SRJ24S05SH99
J2: SAMACSYS_PARTS_USB4110-GF-A; SAMACSYS_PARTS_USB4110GFA
J3: QWIIC_RIGHT_ANGLE; JST04_1MM_RA
J4: 112A-TAAR-R03_ATTEND; 112ATAARR03ATTEND
L1: 68uF; IND_4828-WE-TPC_WRE
MCP73831: ESP32_WROVER_SPARKFUN-IC-POWER_MCP73831; ESP32_WROVER_SPARKFUN-IC-POWER_SOT23-5
PFMF.050.1: ESP32C6_VARISTORCN1812; ESP32C6_VARISTOR_CT/CN1812
Q1, Q2: 20V/4.2A/52mΩ/1.4W; ESP32_WROVER_SPARKFUN-DISCRETESEMI_SOT23-3
Q3: SI1308EDL-T1-GE3; SOT65P210X110-3N
R1, R1_PINH, R1_PINH1, R2_PINH, R2_PINH1, R4, R5, R6, R7, R8, R9, R10: 10K; ESP32_WROVER_EAGLE-LTSPICE_R0402
R1_BAT: 200; ESP32_WROVER_EAGLE-LTSPICE_R0402
R1_PWRUSB: 100K; ESP32_WROVER_EAGLE-LTSPICE_R0402
R2: 2.2; ESP32_WROVER_EAGLE-LTSPICE_R0402
R2-USB, R2-USB1: 5k1; ESP32_WROVER_EAGLE-LTSPICE_R0402
R2_BAT: 2K; ESP32_WROVER_EAGLE-LTSPICE_R0402
R3: 0.47; ESP32_WROVER_EAGLE-LTSPICE_R0402
RESET_BUTTON: BUTTON_CUSYOMV1; MYBUTTON
R_BOOT: 10K; ESP32_WROVER_EAGLE-LTSPICE_R0402
R_CAPACITOR: 15; ESP32_WROVER_EAGLE-LTSPICE_R0402
R_CHANGE: 10K; ESP32_WROVER_EAGLE-LTSPICE_R0402
R_CL1: 10K; ESP32_WROVER_EAGLE-LTSPICE_R0402
R_RESET: 10K; ESP32_WROVER_EAGLE-LTSPICE_R0402
SENSOR2: ESP32_WROVER_BME680_BME680; ESP32_WROVER_BME680_PSON80P300X300X100-8N
SJ1: SJ
TP1, TP2, TP3, TP4, TP5, TP6, TP7, TP8, TP9, TP10, TP11, TP12, TP13, TP14, TP15, TP16, TP17: TPTP20R; TP20R
U1: W25Q512JVEIQ; SON127P600X800X80-9N
U2: ESP32-C6-WROOM-1-N8; XCVR_ESP32-C6-WROOM-1-N8
U3: DS3231SN#; SOIC127P1032X265-16N
U4: MAX17048G+T10; SON50P200X200X80-9N

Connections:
3V3: C2_BAT2.1, C3.+, C9.1, D7.2 (ANODE), IC1.2 (VDD), IC4.5 (VOUT), J3.2, J4.P4 (VDD), Q2.3 (D), R1.2, R1_PINH1.2, R2_PINH1.2, R5.2, R6.2, R7.2, R8.2, R9.2, R10.2, R_BOOT.2, R_CHANGE.2, R_CL1.2, R_RESET.2, TP16.TP, U1.3 (!WP!(IO2)), U1.7 (!HOLD!/!RESET!(IO3)), U1.8 (VCC), U2.2 (3V3), U3.2 (VCC)
32KHZ: R2_PINH1.1, U2.9 (IO1), U3.1 (32KHZ)
DN: D1.6 (I/O1_2), J2.A7, J2.B7
DP: D1.4 (I/O2_2), J2.A6, J2.B6
EPD_3V3: C7.1, EPD_C5.1, J1.15, J1.16, L1.2, Q2.2 (S), TP17.TP
EPD_3V3_C: Q2.1 (G), R_CL1.1, TP13.TP, U2.18 (IO20)
EPD_BUSY: J1.9, TP9.TP, U2.26 (IO3)
EPD_CS: D6.2, J1.12, R9.1, TP10.TP, U2.11 (IO10)
EPD_DC: J1.11, TP11.TP, U2.5 (IO5)
EPD_RST: J1.10, TP12.TP, U2.21 (IO23)
FLASH_CS: D9.2, R5.1, U1.1 (!CS), U2.12 (IO11)
GDR: J1.2, Q3.1 (G), R4.2
GND: BOOT_BUTTON.1, BOOT_BUTTON.2, C1.2, C1_BAT.2, C1_BAT1.2, C2.2, C2_BAT.2, C2_BAT2.2, C3.-, C4_USB.2, C5.2, C5_USB.2, C6.2, C7.2, C8.2, C9.2, C10.2, C10_SUPERCAP.1, CHANGE_BUTTON.1, CHANGE_BUTTON.2, C_DELAY.2, D1.2 (GND), D3.1 (K), D6.1, D8.1, D9.1, D10.1, D11.1, D12.1, EPD_C1.2, EPD_C2.2, EPD_C5.2, EPD_C6.2, EPD_C7.2, EPD_C8.2, EPD_C9.2, EPD_C10.2, EPD_C11.2, EPD_C12.2, IC1.3 (GND), IC4.2 (VSS), J1.8, J1.17, J1.MP1, J1.MP2, J2.A1, J2.A12, J2.B1, J2.B12, J2.MP1, J2.MP2, J2.MP3, J2.MP4, J3.1, J4.G1 (GND_1), J4.G2 (GND_2), J4.G3 (GND_3), J4.G4 (GND_4), J4.P6 (VSS), MCP73831.2 (VSS), R1_PWRUSB.1, R2.1, R2-USB.2, R2-USB1.1, R2_BAT.1, R4.1, RESET_BUTTON.1, RESET_BUTTON.2, SENSOR2.1 (GND), SENSOR2.5 (SDO), SENSOR2.7 (GND), SJ1.1, TP4.TP, TP5.TP, U1.4 (GND), U1.9 (EXP), U2.1 (GND), U2.28 (GND), U2.29_1 (GND), U2.29_2 (GND), U2.29_3 (GND), U2.29_4 (GND), U2.29_5 (GND), U2.29_6 (GND), U2.29_7 (GND), U2.29_8 (GND), U2.29_9 (GND), U3.13 (GND), U4.1 (CTG), U4.4 (GND), U4.6 (QSTRT), U4.9 (EP)
GPIO8: R1.1, U2.10 (IO8)
I2C_PW: C1.1, C2.1, R1_PINH.2, R2_PINH.2, SENSOR2.2 (CSB), SENSOR2.6 (VDDIO), SENSOR2.8 (VDD), U2.17 (IO19)
INT_RTC: R1_PINH1.1, TP15.TP, U2.8 (IO0), U3.3 (SQW/!INT)
IO/BOOT: BOOT_BUTTON.3, BOOT_BUTTON.4, C6.1, R_BOOT.1, U2.15 (IO9)
IO/CHANGE: C10.1, CHANGE_BUTTON.3, CHANGE_BUTTON.4, R_CHANGE.1, U2.23 (IO15)
MISO: D12.2, J4.P7 (DAT0), R8.1, TP6.TP, U1.2 (DO(IO1)), U2.27 (IO2)
MOSI: D11.2, J1.14, J4.P3 (CMD), R7.1, TP7.TP, U1.5 (DI(IO0)), U2.7 (IO7)
unnamed: EPD_C12.1, J1.24
unnamed: EPD_C10.1, J1.22
unnamed: J2.A5, R2-USB1.2
unnamed: CHG_LED.C, R1_BAT.1
unnamed: C1_BAT1.1, D2.1 (CATHODE), IC4.1 (VIN), IC4.3 (CE), Q1.2 (S)
unnamed: C4.1, D3.2 (A), D4.1 (K)
unnamed: MCP73831.1 (STAT), R1_BAT.2
unnamed: EPD_C8.1, J1.20
unnamed: MCP73831.5 (PROG), R2_BAT.2
unnamed: EPD_C7.1, J1.19
unnamed: J2.B5, R2-USB.1
unnamed: EPD_C6.1, J1.18
unnamed: EPD_C2.1, J1.5
unnamed: EPD_C1.1, J1.4
unnamed: C_DELAY.1, IC1.5 (CT)
unnamed: D7.1 (CATHODE), R_CAPACITOR.1
PREVGH: D5.1 (K), EPD_C9.1, J1.21
PREVGL: D4.2 (A), EPD_C11.1, J1.23
RESE: J1.3, Q3.2 (S), R3.2
RESE': R2.2, R3.1, SJ1.2
RESET: C5.1, IC1.1 (VOUT), RESET_BUTTON.3, RESET_BUTTON.4, R_RESET.1, U2.3 (EN)
RTC_RST: U2.16 (IO18), U3.4 (!RST)
RX: TP2.TP, U2.24 (RXD0/GPIO17)
SCK: D10.2, J1.13, J4.P5 (CLK), R6.1, TP8.TP, U1.6 (CLK), U2.6 (IO6)
SCL: J3.4, R2_PINH.1, SENSOR2.4 (SCK), U2.20 (IO22), U3.16 (SCL), U4.7 (SCL)
SDA: J3.3, R1_PINH.1, SENSOR2.3 (SDI), U2.19 (IO21), U3.15 (SDA), U4.8 (SDA)
SRC: C4.2, D5.2 (A), L1.1, Q3.3 (D)
SS_SD: D8.2, J4.P2 (CD/DAT3), R10.1, U2.4 (IO4)
TX: TP1.TP, U2.25 (TXD0/GPIO16)
USB_D+: D1.3 (I/O2_1), U2.14 (IO13)
USB_D-: D1.1 (I/O1_1), U2.13 (IO12)
VBAT: C2_BAT.1, MCP73831.3 (VBAT), Q1.3 (D), TP3.TP, U4.2 (CELL), U4.3 (VDD)
VBUS: C1_BAT.1, C4_USB.1, C5_USB.1, CHG_LED.A, D1.5 (VBUS), D2.2 (ANODE), MCP73831.4 (VIN), PFMF.050.1.2, Q1.1 (G), R1_PWRUSB.2, TP14.TP
VRTC: C8.1, C10_SUPERCAP.2, R_CAPACITOR.2, U3.14 (VBAT)
VUSB: J2.A4, J2.A9, J2.B4, J2.B9, PFMF.050.1.1

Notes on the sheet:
USB C connector & ESD protection
LDO Voltage Regulator
SD Card
ESP32 C6
Li-Po Battery Charging Controller
E-Paper Drive Circuit
Display Type Selector
E-Paper Display Header
EPD Power
Environmental Sensor BME688
Voltage Supervisor +
Reset & BOOT/IO Button
Battery Charge Level
External NOR Flash 64MB
SPI ESD
Protection
Lines
Qwiic / Stemma QT
Test Pads
RTC Module DS3231SN

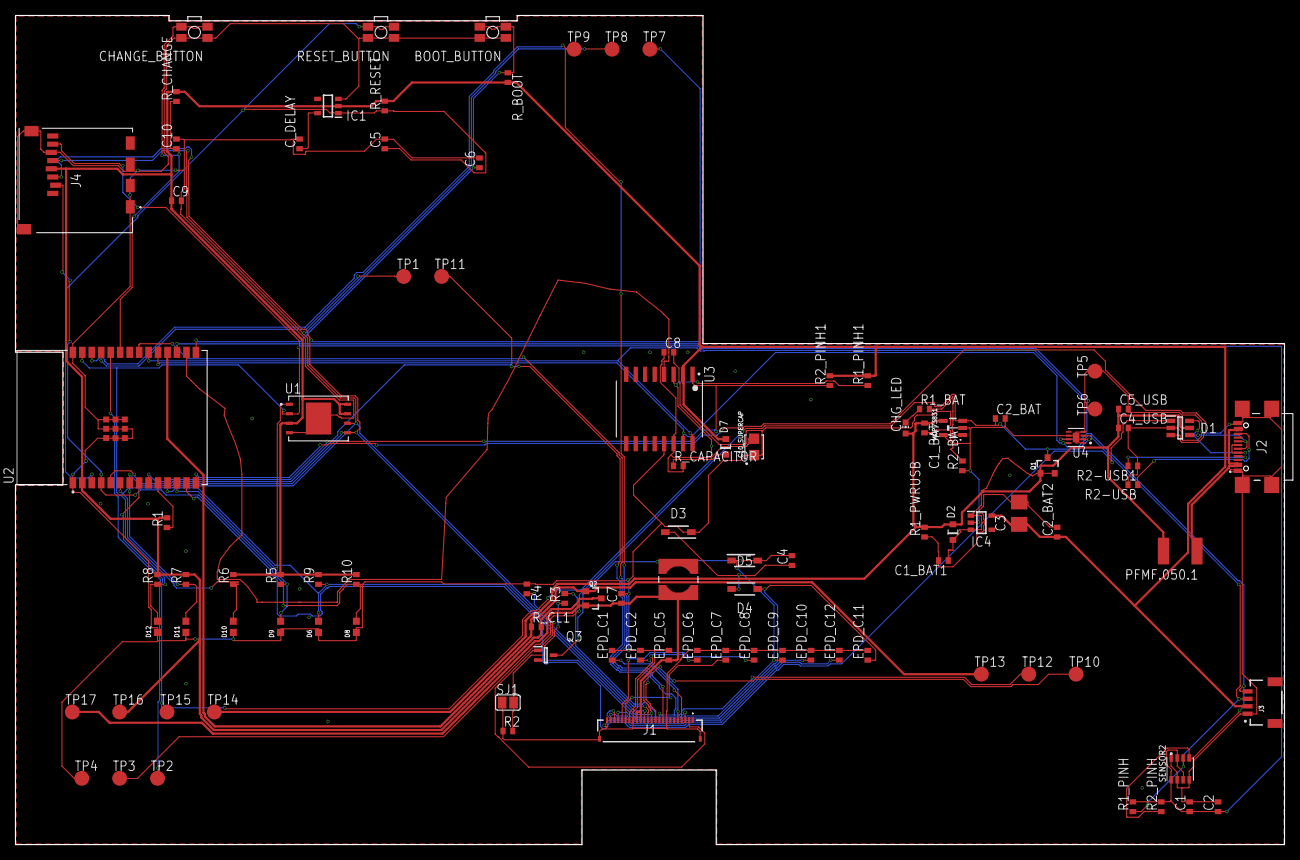
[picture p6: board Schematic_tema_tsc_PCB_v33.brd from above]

Board: 2 copper layers, 170.2 x 111.2 mm, 103 parts (0 on the bottom side), 55 nets.

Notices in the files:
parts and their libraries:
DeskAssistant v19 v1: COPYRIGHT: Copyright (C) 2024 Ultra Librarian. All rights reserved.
